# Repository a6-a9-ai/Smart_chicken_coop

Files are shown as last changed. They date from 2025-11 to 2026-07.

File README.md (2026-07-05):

# smartChicken: Multi-Sensor Environmental & Security System

A lightweight, event-driven application built on **Zephyr RTOS** for multi-sensor data collection and Bluetooth Low Energy (BLE) alert broadcasting.

## Project Structure
* **`soft_nRF`**: Core sensor hub firmware utilizing cooperative and preemptive workqueues to schedule non-blocking sensor sampling and manage UART/PWM peripherals.
* **`soft_nRF_R`**: Standalone receiver node logic that scans for specific broadcasting frames and drives physical LED indicators based on alert states.
* **`PCBs`**: Design files for 3 custom boards handling solar power adaptation, battery storage, and 3.3V/5V regulated power delivery.
* **`3D_prints`**: Mechanical manufacturing models, including a structural base support for a 24-cell PV solar panel.

---
<details>
  <summary> Power supply layout </summary>
  
  PCB Layout Rendering
</details>

<details>
  <summary> Receptor board layout </summary>
  
  PCB Layout Rendering
</details>

<details>
  <summary> Connector board layout </summary>
  
  PCB Layout Rendering
</details>

<details>
  <summary> Power supply routes </summary>
  
  PCB Layout Rendering
</details>

<details>
  <summary> Power supply 3D board </summary>
  
  PCB Layout Rendering
</details>

<details>
  <summary> Connector 3D board </summary>
  
  PCB Layout Rendering
</details>

<details>
  <summary> Receptor 3D board </summary>
  
  PCB Layout Rendering
</details>

## Technical Specifications

### 1. Concurrency Contexts (`main.c`)
The system offloads tasks to Zephyr's workqueue framework to avoid continuous thread shifting:
*   **`sensor_wq`**: Cooperative workqueue (Stack: 1024, Priority: 5) dedicated to regular, periodic sensor sampling routines.
*   **`critical_wq`**: Preemptive workqueue (Stack: 1024, Priority: -4) reserved for immediate actuator responses.

### 2. Peripheral & Sensor Matrix
*   **SCD30**: Interfaced via I2C (`DT_NODELABEL(scd30)`). It measures CO2, temperature, and humidity. Integrity is verified through a Sensirion-compliant polynomial `0x31` CRC-8 check.
*   **DHT11**: Connected via GPIO (`gpio0`, pin 4). Measures environmental metrics every 5000 ms using single-wire signaling.
*   **PIR Sensor**: Connected via GPIO (`gpio1`, pin 8). Polled asynchronously every 2500 ms to capture motion vectors.
*   **Photodiode**: Monitors ambient light variations.
*   **Fan Actuator**: Driven by hardware PWM (`DT_ALIAS(pwm_led0)`) with a baseline period of 40 µs.
*   **UART Host Link**: Mapped to `uart20` (RX: P1.05, TX: P1.04). Operates with a 4-byte receive buffer and a 1000 µs window timeout for ESP32 communications.

### 3. Thresholds & Control Hysteresis
*   **CO2 Threshold**: Registers an alert state if carbon dioxide levels exceed 1000.0 ppm.
*   **Fan & Thermal Management (`DHT11.c`)**:
    *   Turns **ON** (100% duty cycle) if Temperature > 23°C (`FAN_THRESHOLD_TEMP_SUP`).
    *   Turns **OFF** (0% duty cycle) when Temperature drops below 23°C.

### 4. Custom BLE Alert Protocol
The transmitting hub identifies itself as `"smartChicken"`. Discovered alerts modify a 1-byte payload packaged within a Custom Manufacturer Data sequence using Company ID `0x0D06`:

| Bit Index | Packet Macro Flag | Trigger Condition |
| :--- | :--- | :--- |
| **Bit 0** | `BLE_PAQUET_TEMP_BIT` | Temperature exceeds 23°C |
| **Bit 1** | `BLE_PAQUET_GAS_BIT` | SCD30 calculated CO2 exceeds 1000.0 ppm |
| **Bit 2** | `BLE_PAQUET_ATTACK_BIT` | Motion registered by the PIR sensor line |

The receiver application (`soft_nRF_R`) scans for this explicit frame, decodes the bit field state, and directly alters the status of `led0`, `led1`, and `led2`.

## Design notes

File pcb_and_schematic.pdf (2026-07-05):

# 2 GND

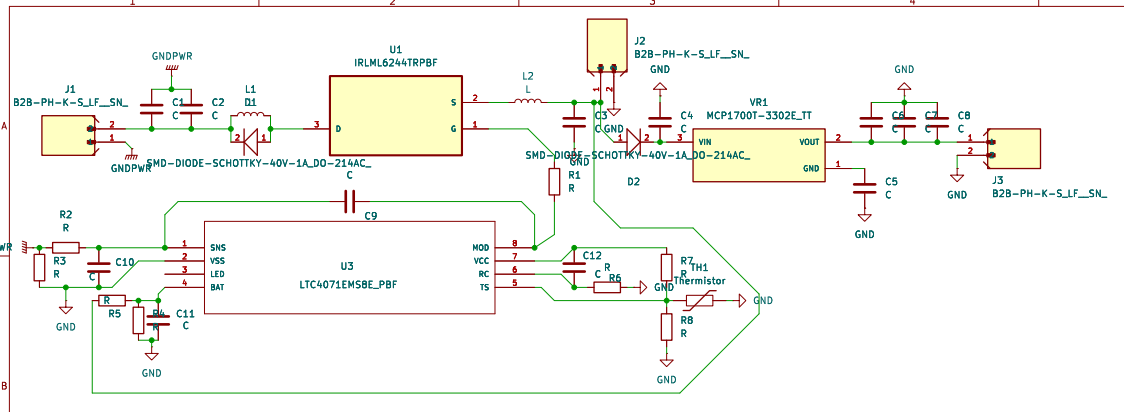
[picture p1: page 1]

Id: 1/1 Title: File: energy_test_PCB.kicad_sch Sheet: /

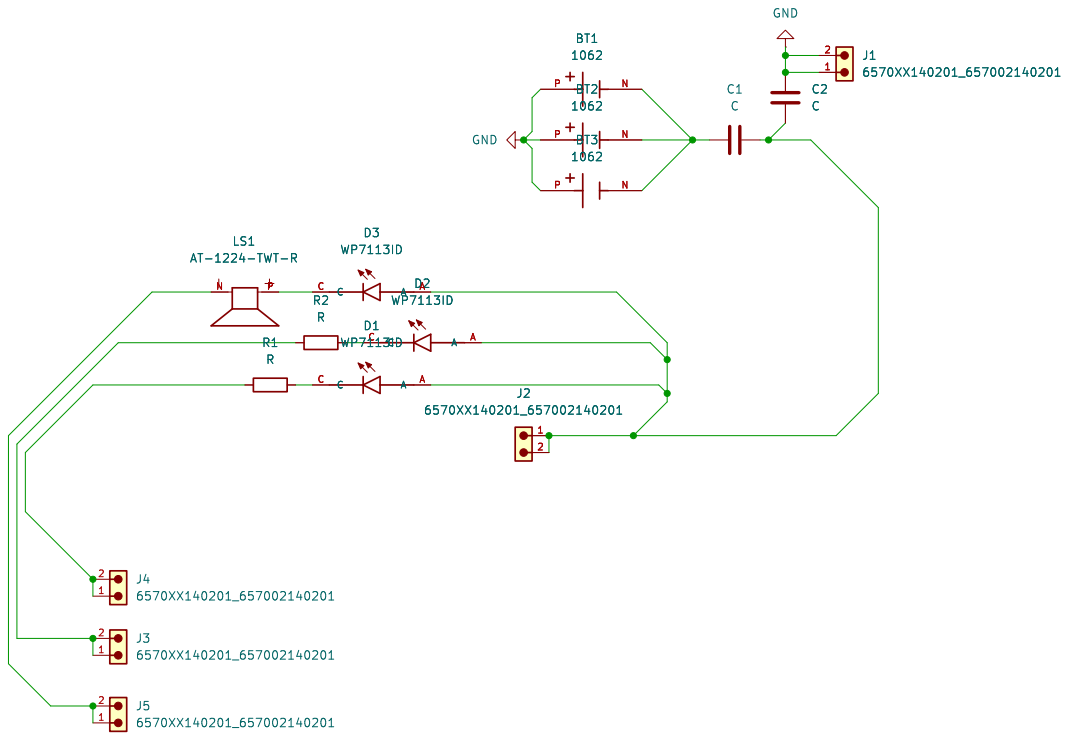
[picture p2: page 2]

Id: 1/1 Title: File: receiver.kicad_sch Sheet: /

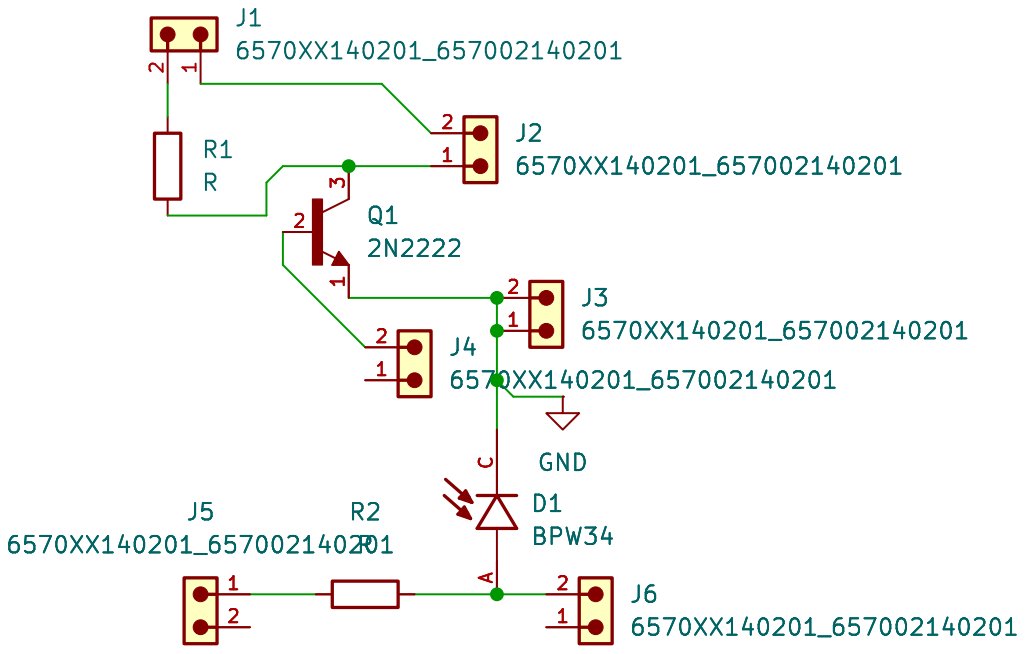
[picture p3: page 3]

Id: 1/1 Title: File: connector.kicad_sch Sheet: /

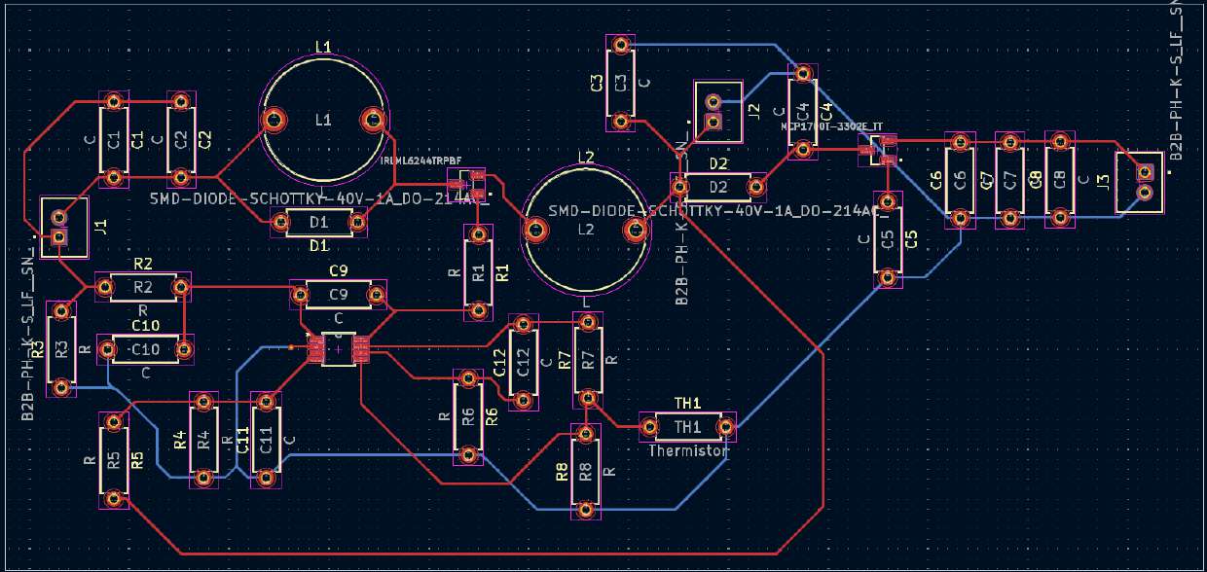
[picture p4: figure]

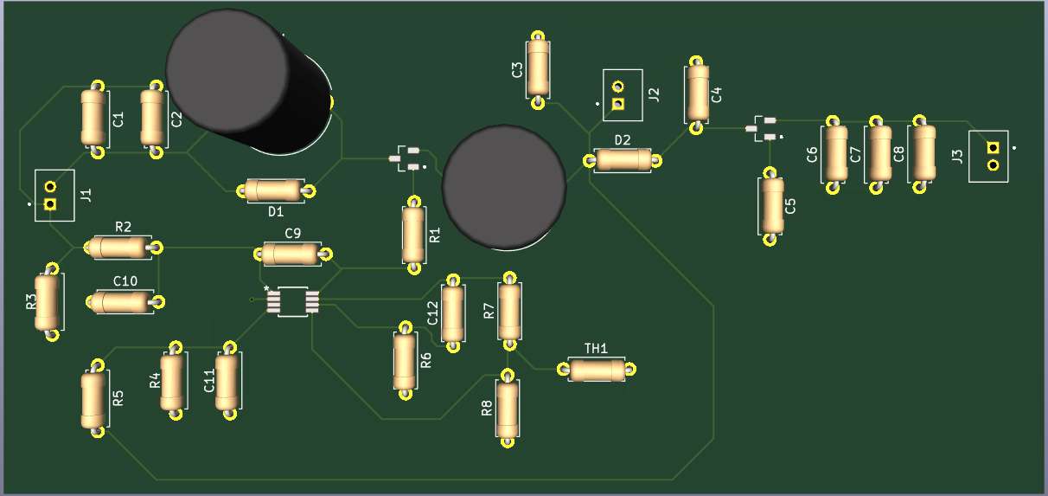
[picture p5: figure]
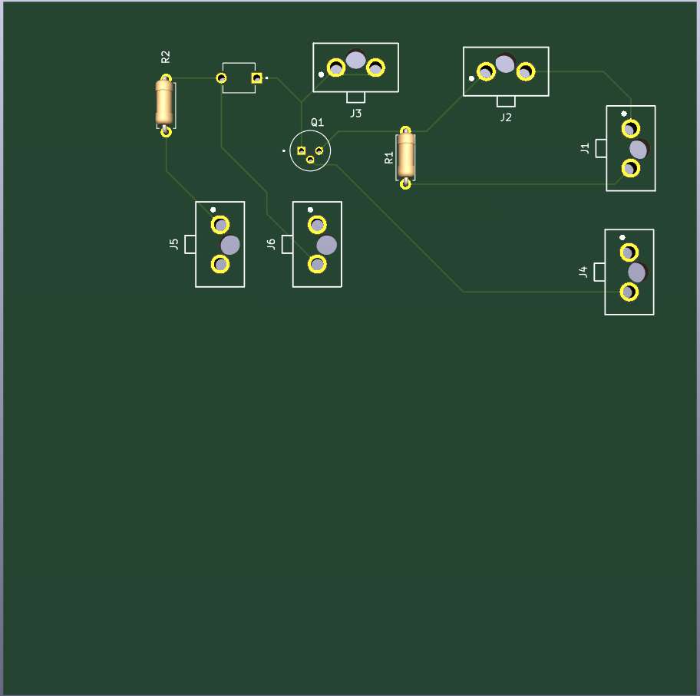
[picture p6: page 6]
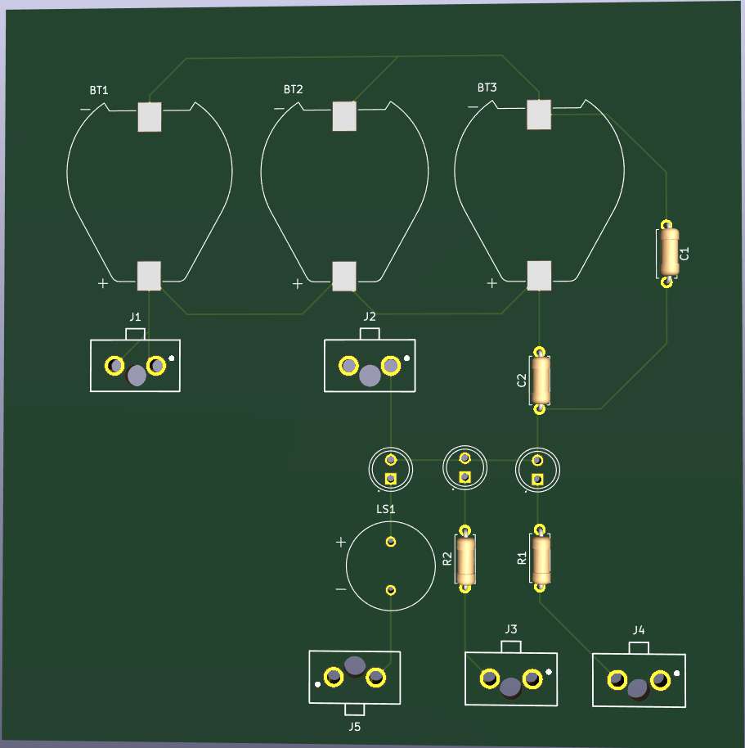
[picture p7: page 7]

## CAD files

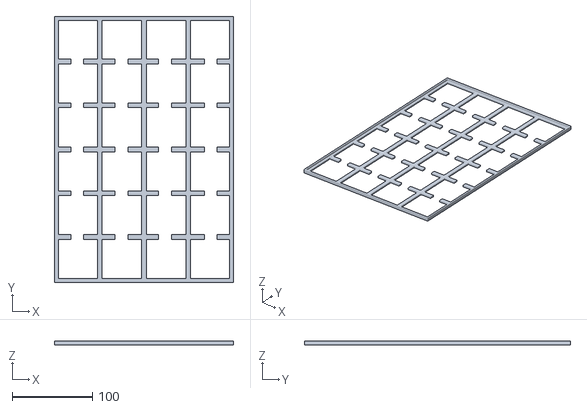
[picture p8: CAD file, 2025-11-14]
3D_prints/support_pv_bottom_V_1 v10.stl
223.0 x 330.5 x 5.50

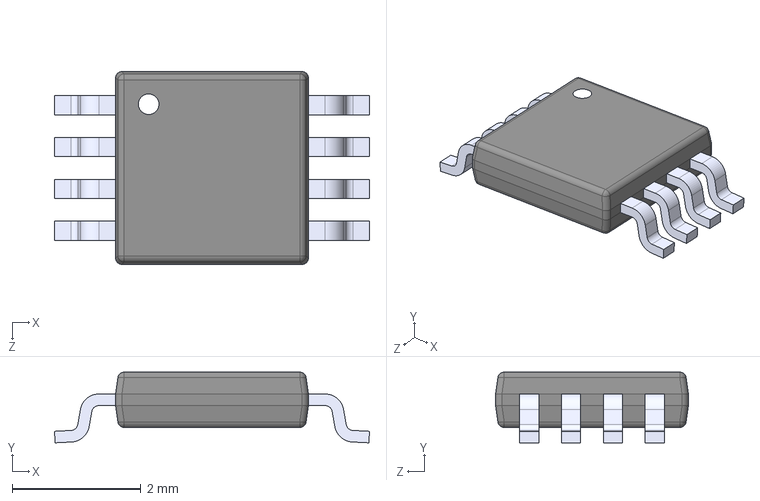
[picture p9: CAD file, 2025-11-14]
PCB_footprints/LTC4071EMS8E_PBF.step
4.90 x 1.10 x 3.00 mm

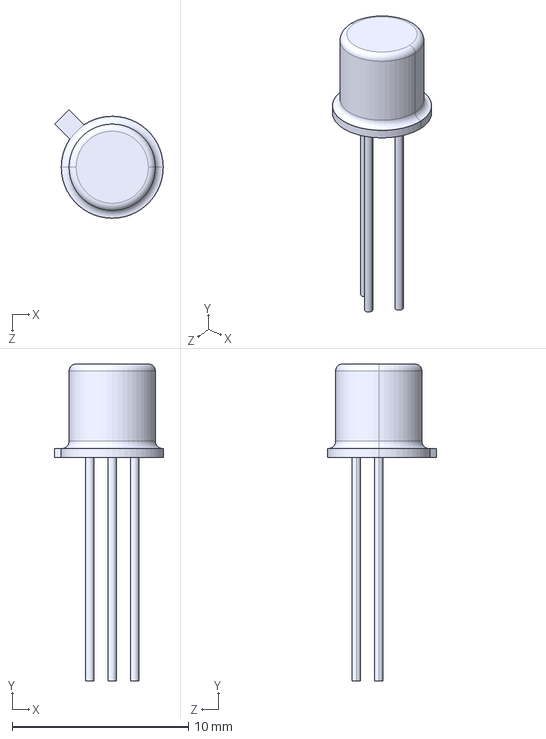
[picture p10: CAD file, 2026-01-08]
PCBs/main_PCB_V1/PCB_footprints_connector/2N2222.step
6.17 x 18.0 x 6.17 mm

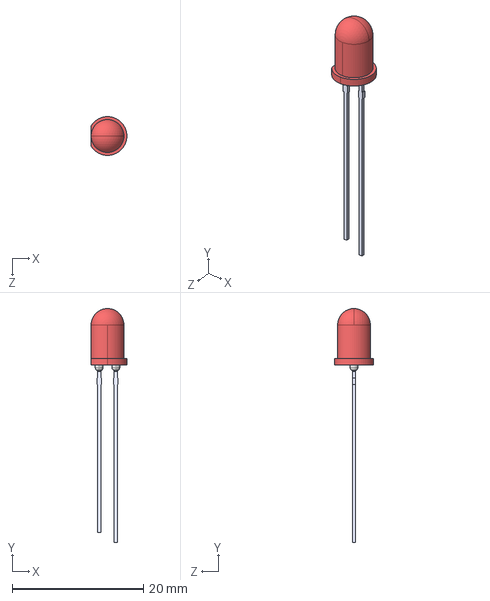
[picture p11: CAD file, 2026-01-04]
PCBs/receiver_PCB/PCB_footprints_receiver/WP7113ID.step
5.45 x 35.6 x 5.90 mm

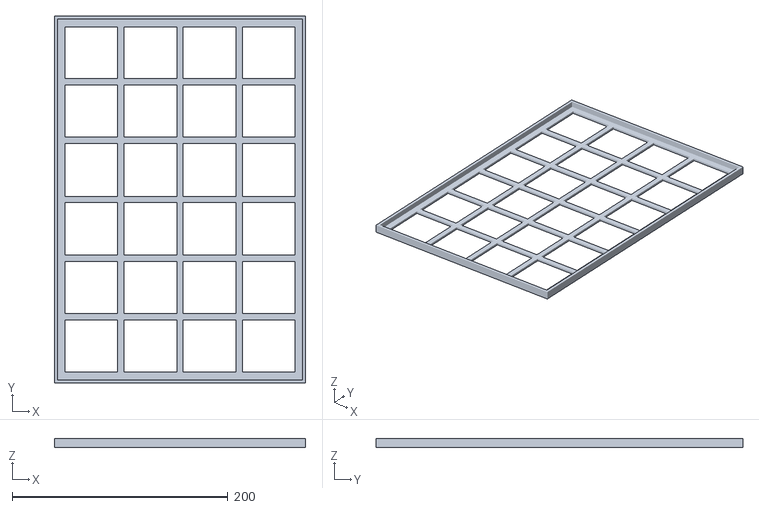
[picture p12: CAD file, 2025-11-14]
3D_prints/support_pv_top_V_1 v3.stl
233.0 x 340.5 x 8.50

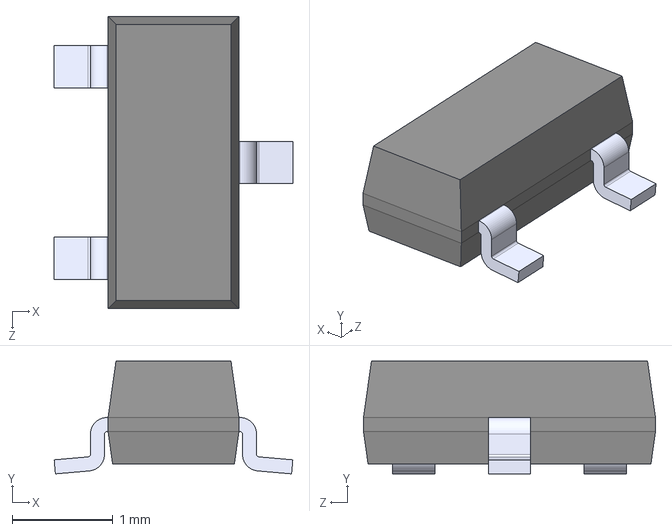
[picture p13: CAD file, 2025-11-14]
PCB_footprints/MCP1700T-3302E_TT.step
2.37 x 1.12 x 2.90 mm

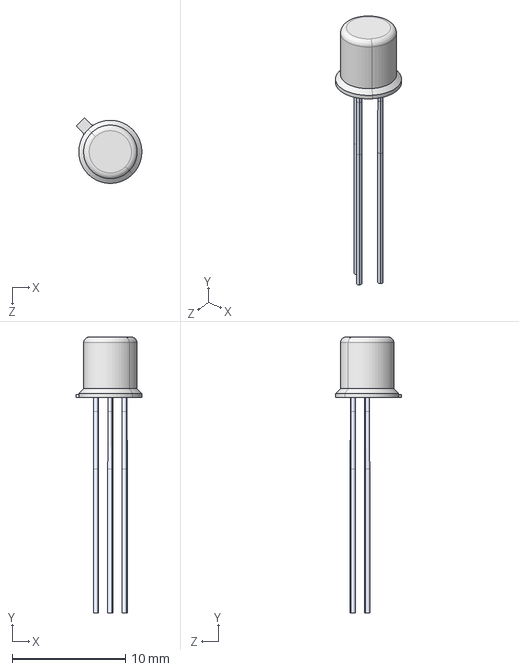
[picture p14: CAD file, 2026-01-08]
PCBs/main_PCB_V1/PCB_footprints_connector/2N2222A.step
5.80 x 24.4 x 5.80 mm

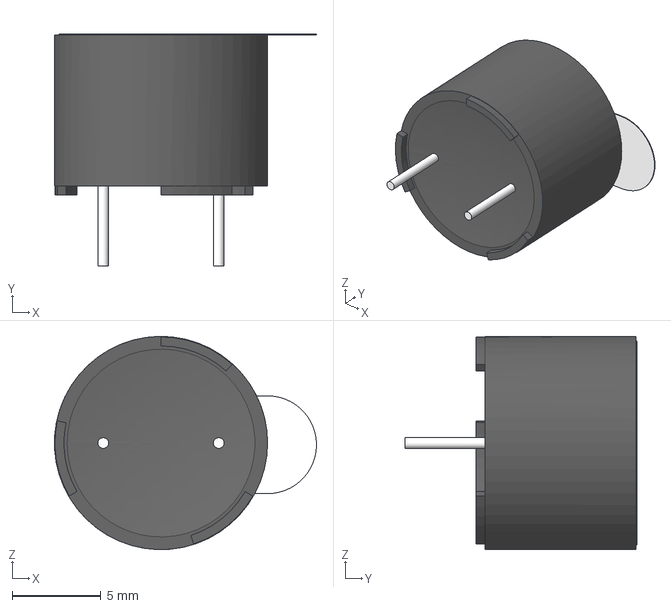
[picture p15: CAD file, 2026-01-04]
PCBs/receiver_PCB/PCB_footprints_receiver/AT-1224-TWT-R.step
14.7 x 13.1 x 12.0 mm

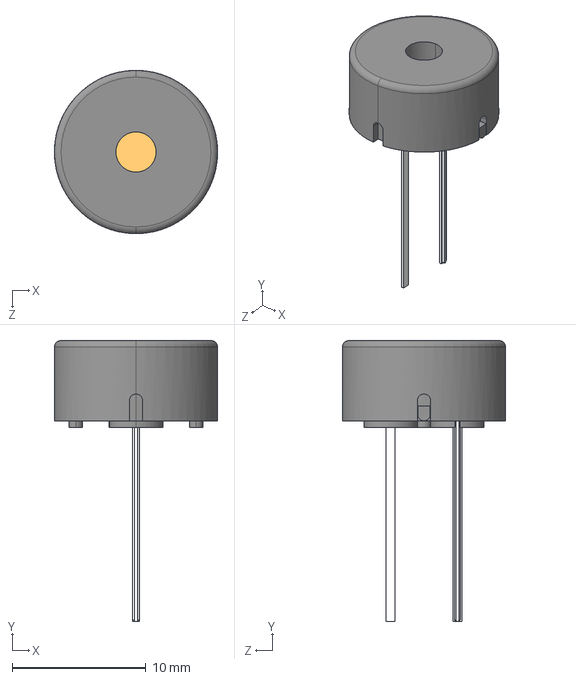
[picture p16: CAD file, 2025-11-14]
PCB_footprints/PS1240P02BT.step
12.2 x 21.0 x 12.2 mm

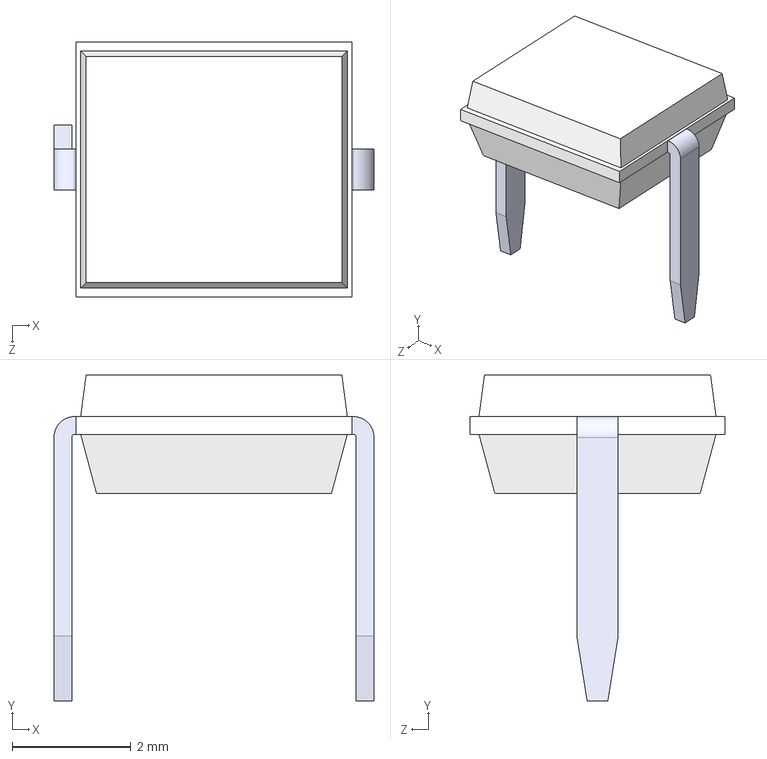
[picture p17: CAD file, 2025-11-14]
PCBs/main_PCB_V1/PCB_footprints_connector/BPW34.step
5.40 x 5.50 x 4.30 mm

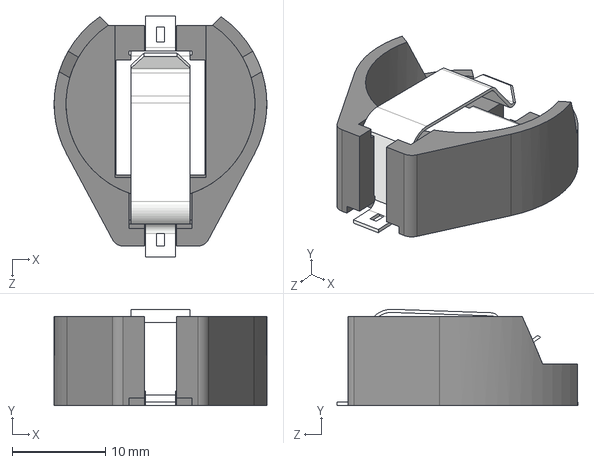
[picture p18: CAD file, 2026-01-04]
PCBs/receiver_PCB/PCB_footprints_receiver/1062.step
22.8 x 10.3 x 25.8 mm

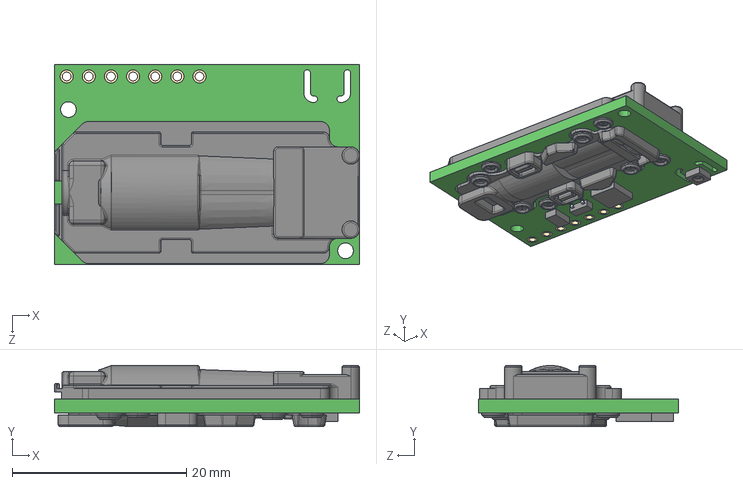
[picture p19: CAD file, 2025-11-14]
PCB_footprints/SCD30.step
35.0 x 7.00 x 23.0 mm

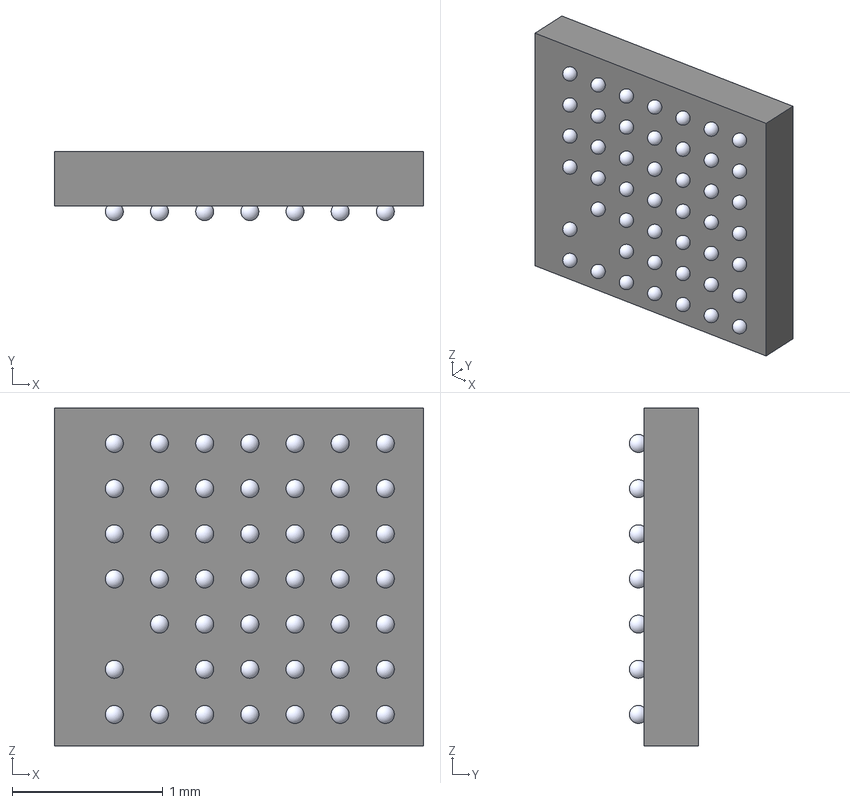
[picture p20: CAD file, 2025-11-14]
PCBs/receiver_PCB/PCB_footprints_receiver/NRF54L15-CAAA-R.step
2.45 x 0.46 x 2.25 mm
Body_Solid1
Body002_Solid1
BALL_0001
BALL_0002
BALL_0003
BALL_0004
BALL_0005
BALL_0006
BALL_0007
BALL_0008
BALL_0009
BALL_0010
BALL_0011
BALL_0012
BALL_0013
BALL_0014
BALL_0015
BALL_0016
BALL_0017
BALL_0018
BALL_0019
BALL_0020
BALL_0021
BALL_0022
BALL_0023
BALL_0024
BALL_0025
BALL_0026
BALL_0027
BALL_0028
BALL_0029
BALL_0030
BALL_0031
BALL_0032
BALL_0033
BALL_0034
BALL_0035
BALL_0036
BALL_0037
BALL_0038
BALL_0039
BALL_0040
BALL_0041
BALL_0042
BALL_0043
BALL_0044
BALL_0045
BALL_0046
BALL_0047

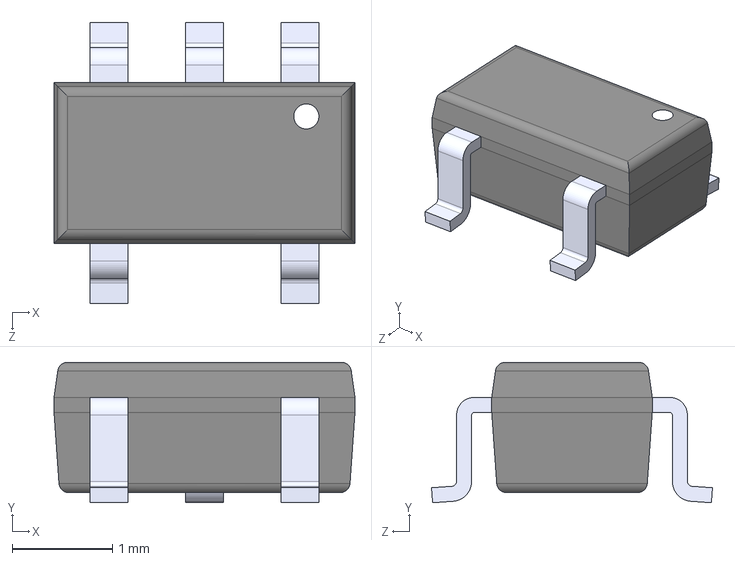
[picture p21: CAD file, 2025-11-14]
PCB_footprints/AP2112K-3.3TRG1.step
3.00 x 1.40 x 2.80 mm

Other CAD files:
PCB_footprints/2450AT18A100E.step
PCB_footprints/FTSH-105-01-F-DV-P-TR.step
PCB_footprints/SMD-DIODE-SCHOTTKY-40V-1A_DO-214AC_.step
PCB_footprints/MCP1640T-I_CHY.step
PCB_footprints/22-28-4030.step
PCB_footprints/B2B-PH-K-S_LF__SN_.step
PCB_footprints/BQ2000PN-B5.step
PCB_footprints/CMC-4015-40P.step
PCB_footprints/DHT11.step
PCB_footprints/IRLML6244TRPBF.step
PCB_footprints/LM317T.step
PCB_footprints/LM317TG.step
PCB_footprints/LM317T_LF01.step
PCB_footprints/MCP602-I_P.step
PCB_footprints/RFM95W-915S2.step

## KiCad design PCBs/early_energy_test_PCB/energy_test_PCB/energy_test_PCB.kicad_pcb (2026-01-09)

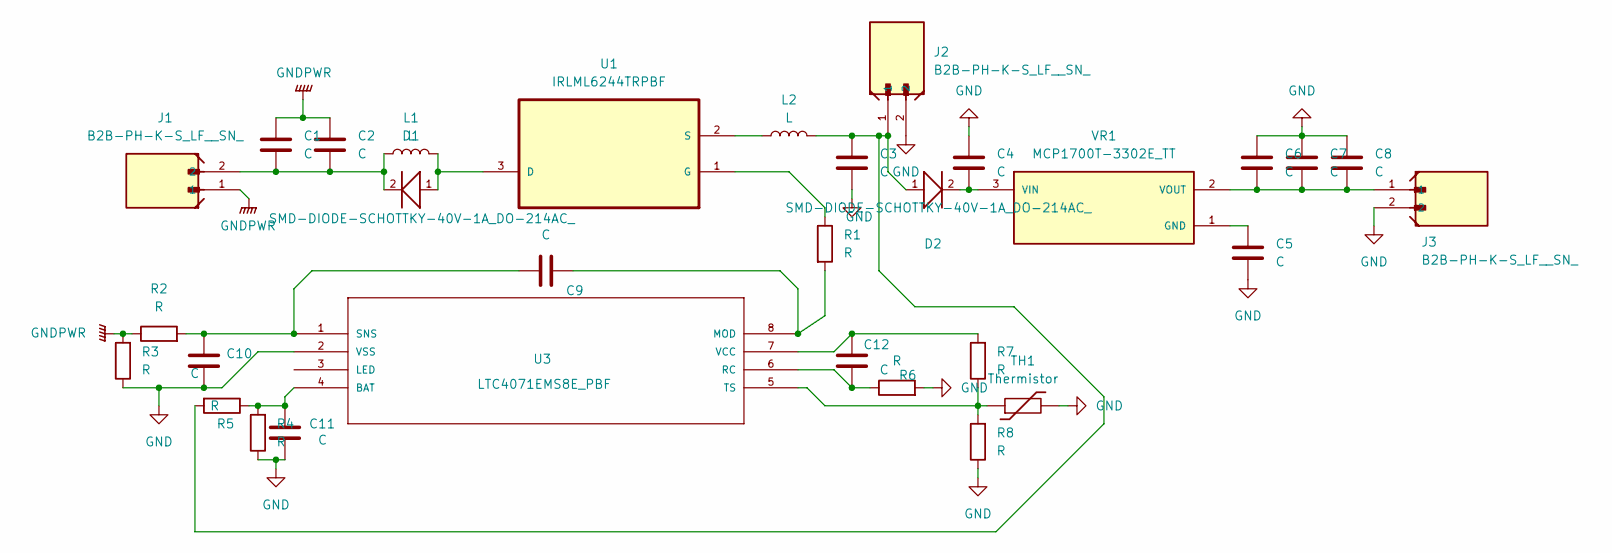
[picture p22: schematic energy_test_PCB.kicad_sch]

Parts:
C1, C2, C3, C4, C5, C6, C7, C8, C9, C10, C11, C12: C; R_Axial_DIN0207_L6.3mm_D2.5mm_P7.62mm_Horizontal
D1, D2: SMD-DIODE-SCHOTTKY-40V-1A_DO-214AC_; R_Axial_DIN0207_L6.3mm_D2.5mm_P7.62mm_Horizontal; MPN 1N5819
J1, J2, J3: B2B-PH-K-S_LF__SN_; JST_B2B-PH-K-S_LF__SN_
L1, L2: L; L_Radial_D12.0mm_P10.00mm_Neosid_SD12_style1
R1, R2, R3, R4, R5, R6, R7, R8: R; R_Axial_DIN0207_L6.3mm_D2.5mm_P7.62mm_Horizontal
TH1: Thermistor; R_Axial_DIN0207_L6.3mm_D2.5mm_P7.62mm_Horizontal
U1: IRLML6244TRPBF; SOT95P237X112-3N; MPN IRLML6244TRPBF
U3: LTC4071EMS8E_PBF; MSOP-8_MS; MANUFACTURER_PART_NUMBER ltc4071ems8e#pbf
VR1: MCP1700T-3302E_TT; SOT95P237X112-3N; PARTREV E

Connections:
GND: C3.2, C4.1, C5.2, C6.1, C7.1, C8.1, C10.1, C11.1, J2.2, J3.2, R3.1, R4.1, R6.2, R8.1, TH1.2, U3.2 (VSS)
GNDPWR: C1.1, C2.1, J1.1, R2.1, R3.2
unnamed: C1.2, C2.2, D1.2, J1.2, L1.1
unnamed: C3.1, D2.1, J2.1, L2.2, R5.2
unnamed: D1.1, L1.2, U1.3 (D)
unnamed: R1.1, U1.1 (G)
unnamed: L2.1, U1.2 (S)
unnamed: C11.2, R4.2, R5.1, U3.4 (BAT)
unnamed: C9.2, R1.2, U3.8 (MOD)
unnamed: C12.1, R6.1, U3.6 (RC)
unnamed: C9.1, C10.2, R2.2, U3.1 (SNS)
unnamed: R7.1, R8.2, TH1.1, U3.5 (TS)
unnamed: C12.2, R7.2, U3.7 (VCC)
unnamed: C5.1, VR1.1 (GND)
unnamed: C4.2, D2.2, VR1.3 (VIN)
unnamed: C6.2, C7.2, C8.2, J3.1, VR1.2 (VOUT)

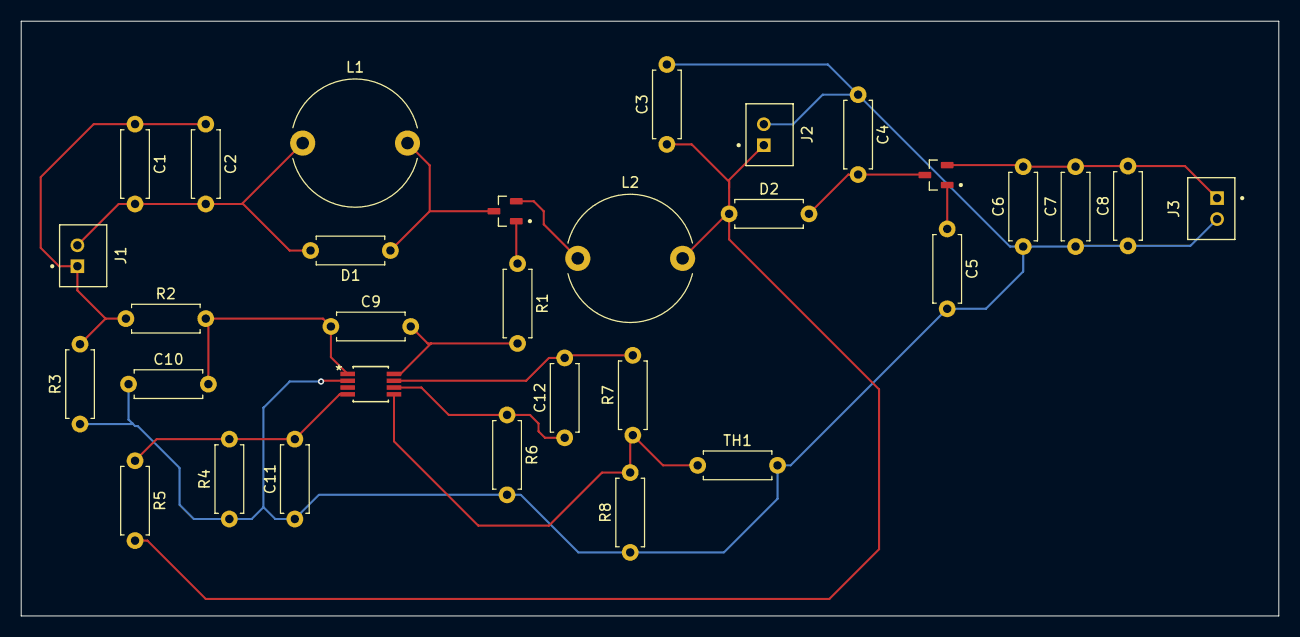
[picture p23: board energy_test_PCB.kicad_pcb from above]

Board: 2 copper layers, 120.0 x 56.8 mm, 31 parts (0 on the bottom side), 16 nets.

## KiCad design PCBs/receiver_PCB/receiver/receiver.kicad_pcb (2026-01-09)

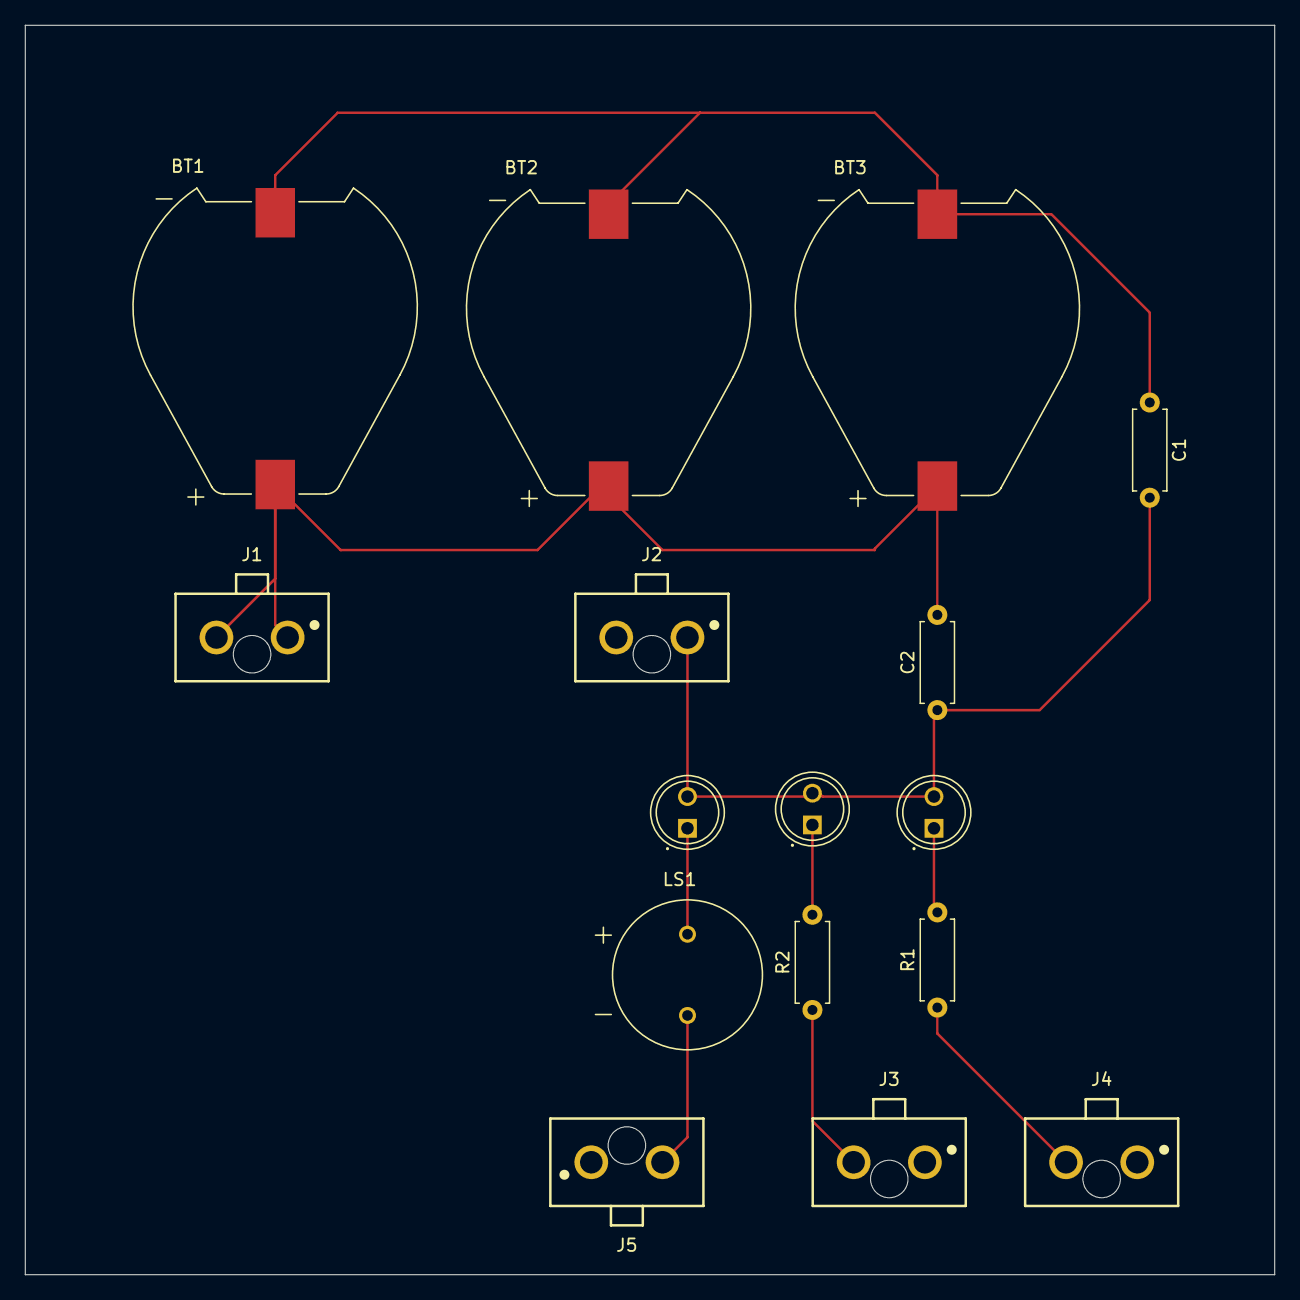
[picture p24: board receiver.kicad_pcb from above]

Board: 2 copper layers, 100.0 x 100.0 mm, 16 parts (0 on the bottom side), 9 nets.

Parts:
BT1, BT2, BT3: 1062; BAT_1062
C1, C2: C; R_Axial_DIN0207_L6.3mm_D2.5mm_P7.62mm_Horizontal
D1, D2, D3: WP7113ID; LED_WP7113ID
J1, J2, J3, J4, J5: 6570XX140201_657002140201; 657002140201
LS1: AT-1224-TWT-R; XDCR_AT-1224-TWT-R
R1, R2: R; R_Axial_DIN0207_L6.3mm_D2.5mm_P7.62mm_Horizontal

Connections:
GND: BT1.P, BT2.P, BT3.P, C2.2, J1.1, J1.2
unnamed: BT1.N, BT2.N, BT3.N, C1.1
unnamed: C1.2, C2.1, D1.A, D2.A, D3.A, J2.1
unnamed: D1.C, R1.2
unnamed: D2.C, R2.2
unnamed: D3.C, LS1.P
unnamed: J3.2, R2.1
unnamed: J4.2, R1.1
unnamed: J5.2, LS1.N

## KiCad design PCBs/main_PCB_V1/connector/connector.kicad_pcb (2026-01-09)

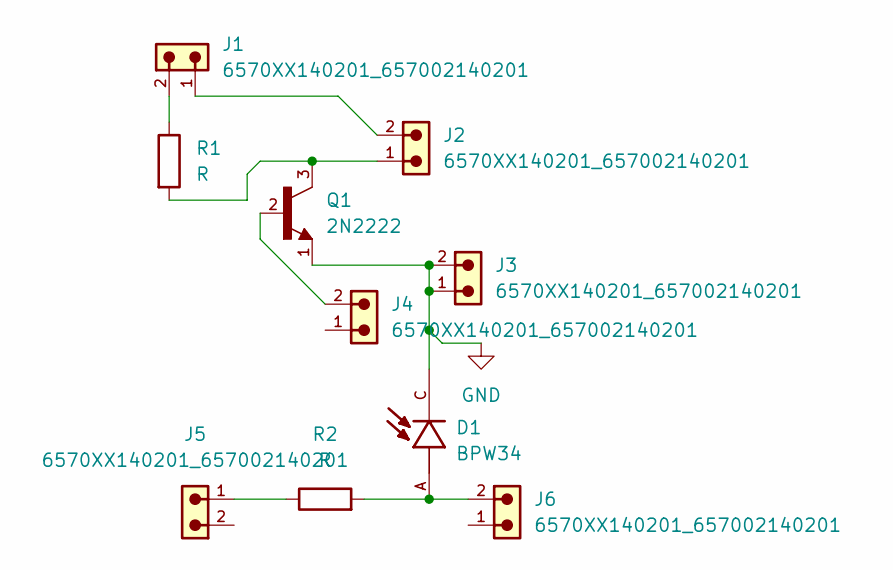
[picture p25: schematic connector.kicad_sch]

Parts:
D1: BPW34; DIO_BPW34; PARTREV 2.1
J1, J2, J3, J4, J5, J6: 6570XX140201_657002140201; 657002140201
Q1: 2N2222; TO127P584H533-3; PARTREV January 1989
R1, R2: R; R_Axial_DIN0207_L6.3mm_D2.5mm_P7.62mm_Horizontal

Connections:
GND: D1.C, J3.1, J3.2, Q1.1
unnamed: D1.A, J6.2, R2.2
unnamed: J1.1, J2.2
unnamed: J1.2, R1.1
unnamed: J2.1, Q1.3, R1.2
unnamed: J4.2, Q1.2
unnamed: J5.1, R2.1

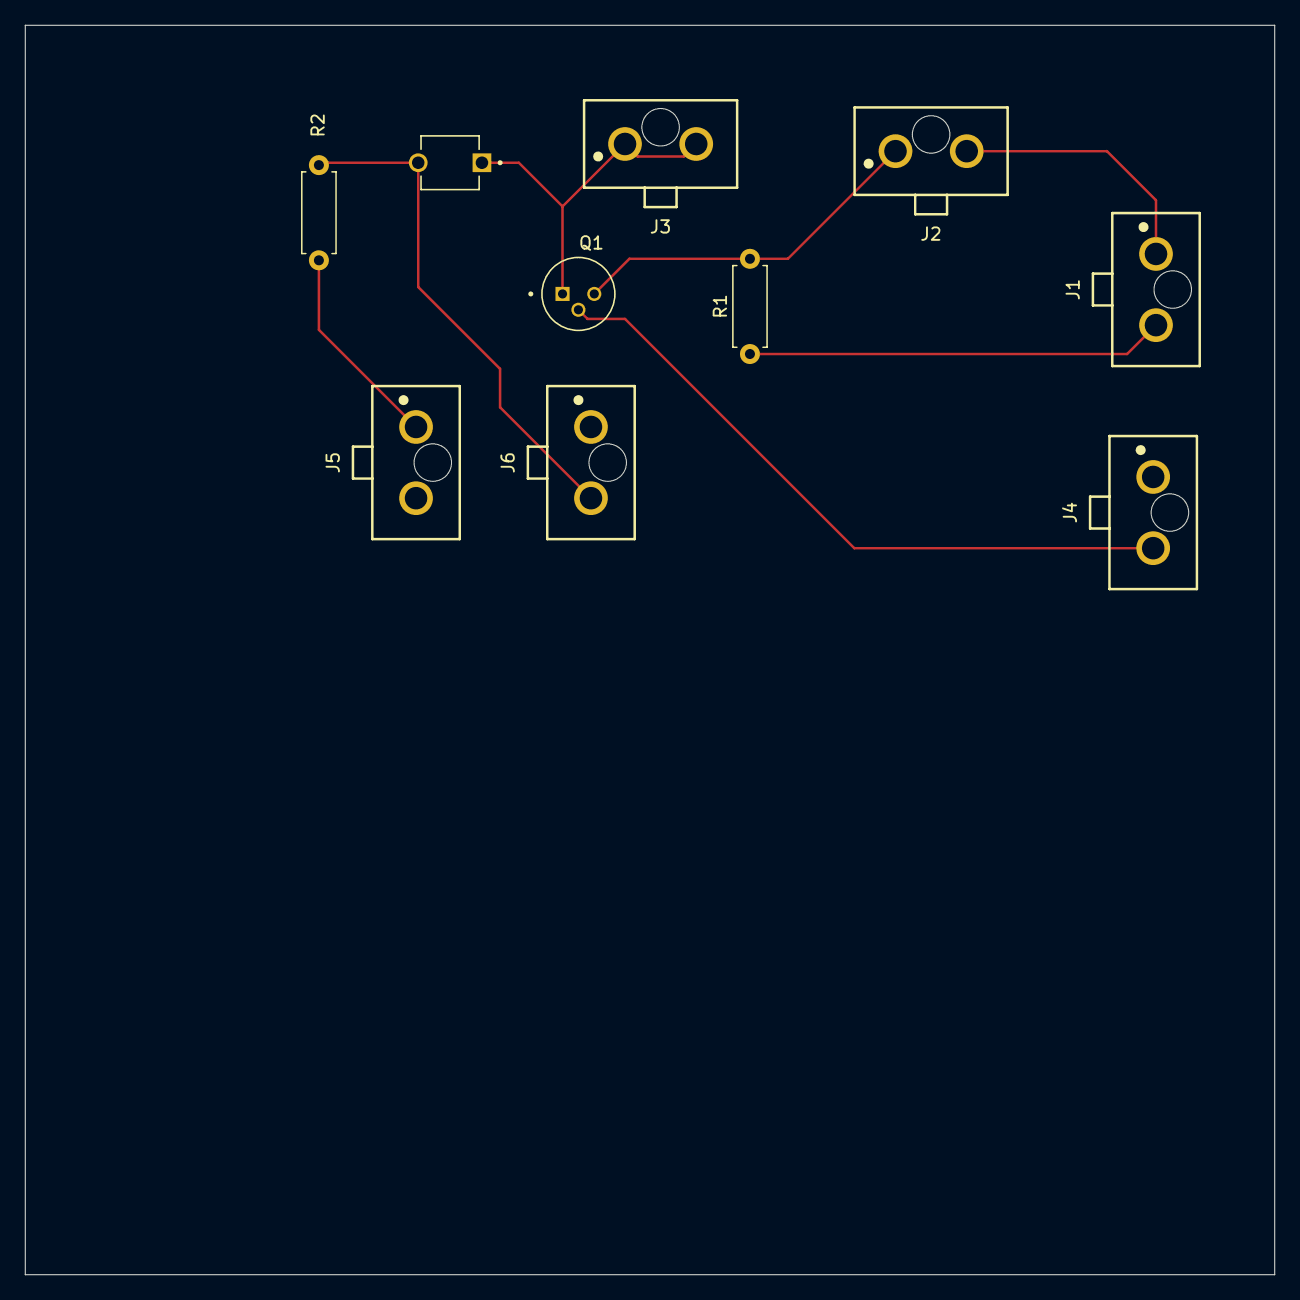
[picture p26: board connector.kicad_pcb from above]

Board: 2 copper layers, 100.0 x 100.0 mm, 10 parts (0 on the bottom side), 7 nets.

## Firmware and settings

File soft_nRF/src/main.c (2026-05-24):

/*******************************************************************************/
/*::::'######::'##::::'##:'####::'######::'##:::'##:'########:'##::: ##::::::::*/
/*:::'##... ##: ##:::: ##:. ##::'##... ##: ##::'##:: ##.....:: ###:: ##::::::::*/
/*::: ##:::..:: ##:::: ##:: ##:: ##:::..:: ##:'##::: ##::::::: ####: ##::::::::*/
/*::: ##::::::: #########:: ##:: ##::::::: #####:::: ######::: ## ## ##::::::::*/
/*::: ##::::::: ##.... ##:: ##:: ##::::::: ##. ##::: ##...:::: ##. ####::::::::*/
/*::: ##::: ##: ##:::: ##:: ##:: ##::: ##: ##:. ##:: ##::::::: ##:. ###::::::::*/
/*:::. ######:: ##:::: ##:'####:. ######:: ##::. ##: ########: ##::. ##::::::::*/
/*::::......:::..:::::..::....:::......:::..::::..::........::..::::..:::::::::*/
/*::::'######:::'#######:::'#######::'########:::::main.c::::::::::::::::::::::*/
/*:::'##... ##:'##.... ##:'##.... ##: ##.... ##::::::::::::::::::::::::::::::::*/
/*::: ##:::..:: ##:::: ##: ##:::: ##: ##:::: ##::::Author: a6a9aia:::::::::::::*/
/*::: ##::::::: ##:::: ##: ##:::: ##: ########:::::<a5a8ahaiac@proton.me>::::::*/
/*::: ##::::::: ##:::: ##: ##:::: ##: ##.....::::::::::::::::::::::::::::::::::*/
/*::: ##::: ##: ##:::: ##: ##:::: ##: ##:::::::::::Created: 2025/09/01:::::::::*/
/*:::. ######::. #######::. #######:: ##:::::::::::Updated: 2026/01/10:::::::::*/
/*::::......::::.......::::.......:::..::::::::::::::::::::::::::::::::::::::::*/
/*******************************************************************************/

#include "DHT11.h"
#include "pir.h"
#include "s30.h"
//#include "SCD30.h"
#include "bluetooth.h"
#include "uart.h"

#include <zephyr/kernel.h>
#include <zephyr/logging/log.h>

LOG_MODULE_REGISTER(main, LOG_LEVEL_INF);

// Sensor workqueue (periodic)
#define SENSOR_WQ_STACK_SIZE                    1024
#define SENSOR_WQ_PRIORITY                      5
K_THREAD_STACK_DEFINE(sensor_stack_area, SENSOR_WQ_STACK_SIZE);
struct k_work_q sensor_wq;

// Critical workqueue
#define CRITICAL_WQ_STACK_SIZE                  1024
#define CRITICAL_WQ_PRIORITY                    -4
K_THREAD_STACK_DEFINE(critical_stack_area, CRITICAL_WQ_STACK_SIZE);
struct k_work_q critical_wq;

// Definition of dht11_periodic_work
K_WORK_DELAYABLE_DEFINE(dht11_periodic_work, dht11_periodic_work_handler);
K_WORK_DELAYABLE_DEFINE(s30_periodic_work, s30_periodic_work_handler);
//K_WORK_DELAYABLE_DEFINE(scd30_periodic_work, scd30_periodic_work_handler);

int main(void){
    if (bluetooth_init() < 0){
        LOG_ERR("Bluetooth init failed");
    }
    if (dht11_init() < 0){
        LOG_ERR("DHT11 init failed!");
    }
    if (pir_init() < 0){
        LOG_ERR("PIR init failed!");
    }
    if (s30_init() < 0){
        LOG_ERR("S30 init failed!");
    }
    //if (scd30_init() < 0){
    //    LOG_ERR("SCD30 init failed!");
    //} else {
    //    k_work_schedule_for_queue(&sensor_wq, &scd30_periodic_work, K_SECONDS(4));
    //}

    // Workqueues initialisation
    k_work_queue_start(&sensor_wq, sensor_stack_area,
                       K_THREAD_STACK_SIZEOF(sensor_stack_area),
                       SENSOR_WQ_PRIORITY, NULL);
    k_work_queue_start(&critical_wq, critical_stack_area,
                       K_THREAD_STACK_SIZEOF(critical_stack_area),
                       CRITICAL_WQ_PRIORITY, NULL);
    LOG_INF("Workqueues started (sensor=%d, critical=%d)", SENSOR_WQ_PRIORITY, CRITICAL_WQ_PRIORITY);

    if (uart_init() < 0){
        LOG_ERR("UART init failed!");
    } else {
        LOG_INF("UART initialized successfully");
    }

    if (fan_control_init() < 0){
        LOG_ERR("Fan control init failed!");
    }
    // Scheduling periodic_sensors_works
    k_work_schedule_for_queue(&sensor_wq, &dht11_periodic_work, K_SECONDS(3));
    k_work_schedule_for_queue(&sensor_wq, &s30_periodic_work, K_SECONDS(7));
    k_work_schedule_for_queue(&sensor_wq, &pir_work, K_MSEC(MEASURE_PIR_PERIOD_MS));

    while(1){
        k_sleep(K_SECONDS(10));
    }
}

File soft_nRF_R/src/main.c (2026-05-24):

/*******************************************************************************/
/*::::'######::'##::::'##:'####::'######::'##:::'##:'########:'##::: ##::::::::*/
/*:::'##... ##: ##:::: ##:. ##::'##... ##: ##::'##:: ##.....:: ###:: ##::::::::*/
/*::: ##:::..:: ##:::: ##:: ##:: ##:::..:: ##:'##::: ##::::::: ####: ##::::::::*/
/*::: ##::::::: #########:: ##:: ##::::::: #####:::: ######::: ## ## ##::::::::*/
/*::: ##::::::: ##.... ##:: ##:: ##::::::: ##. ##::: ##...:::: ##. ####::::::::*/
/*::: ##::: ##: ##:::: ##:: ##:: ##::: ##: ##:. ##:: ##::::::: ##:. ###::::::::*/
/*:::. ######:: ##:::: ##:'####:. ######:: ##::. ##: ########: ##::. ##::::::::*/
/*::::......:::..:::::..::....:::......:::..::::..::........::..::::..:::::::::*/
/*::::'######:::'#######:::'#######::'########:::::main.c::::::::::::::::::::::*/
/*:::'##... ##:'##.... ##:'##.... ##: ##.... ##::::::::::::::::::::::::::::::::*/
/*::: ##:::..:: ##:::: ##: ##:::: ##: ##:::: ##::::Author: a6a9aia:::::::::::::*/
/*::: ##::::::: ##:::: ##: ##:::: ##: ########:::::<a5a8ahaiac@proton.me>::::::*/
/*::: ##::::::: ##:::: ##: ##:::: ##: ##.....::::::::::::::::::::::::::::::::::*/
/*::: ##::: ##: ##:::: ##: ##:::: ##: ##:::::::::::Created: 2025/09/01:::::::::*/
/*:::. ######::. #######::. #######:: ##:::::::::::Updated: 2026/01/10:::::::::*/
/*::::......::::.......::::.......:::..::::::::::::::::::::::::::::::::::::::::*/
/*******************************************************************************/

#include <zephyr/kernel.h>
#include <zephyr/sys/printk.h>
#include "bluetooth.h"

int main(void){
    printk("Starting Scanner Application\n");
    if (scanner_init() < 0){
        printk("Failed to initialize scanner\n");
        return 0;
    }
    while (1){
        k_sleep(K_SECONDS(1));
    }
    return 0;
}

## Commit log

2025-11-14 Add initial PCB footprints and zephyr code for DHT11 ans Fan_management
    Added KiCad symbols in PCB_footprints
    + PCB_footprints_save directories. Included simulation script
    + initial source files for nRF project.
    (the fan is on when temperature is over 23°C according to DHT11.
    Every process is processed through workqueues defined in main.c.
    [22-28-4030.step, 2450AT18A100E.step, AP2112K-3.3TRG1.step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]
2025-11-14 Add PCB design + 3D print files
    Added support structure STL files for PV module.
    Included new PCB design for early energy test PCB.
    + footprints updates
    [LTC4071EMS8E_PBF.step, MCP1700T-3302E_TT.step, energy_test_PCB.kicad_pcb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]
2025-11-15 merging fan_control.c in DHT11.c
    merging fan_control.c in DHT11.c
    + workqueue structure for BLE alert
    + fan management optimisation
2025-11-19 ble alerte update
    fixed an issue about wq_critical pausing, fixed by scheduling bt_le_adv_stop() through new ble_stop_alerte_temp_work
    [DHT11.c, DHT11.h, bluetooth.c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]
2026-01-04 Add receiver PCB files and update energy test PCB (V0)
    Added new receiver PCB design files, including footprints, symbols, 3D models, and project backups. Updated early energy test PCB files with detailed board layout and schematic content.
    [1062.step, AT-1224-TWT-R.step, NRF54L15-CAAA-R.step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]
2026-01-08 add the 3rd pcb
    Added new connector footprints, symbols, and STEP models for 2N2222, 2N2222A, BPW34, and 657002140201 in main_PCB_V1. Created new connector PCB project files. Updated .gitignore to exclude new backup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
    [2N2222.step, 2N2222A.step, BPW34.step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]
2026-01-09 Add soft_nRF_R project and update receiver PCB
    Added new soft_nRF_R firmware project with initial source files. Updated receiver PCB design to use Wurth Elektronik connectors, revised net assignments, and replaced legacy footprints. Adjusted .gitignore for new build directory. Minor updates to other PCB and source files for consistency.
    [connector.kicad_pcb, energy_test_PCB.kicad_pcb, receiver.kicad_pcb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]
2026-07-05 docs: update README, add PCB layouts & 3D visuals
